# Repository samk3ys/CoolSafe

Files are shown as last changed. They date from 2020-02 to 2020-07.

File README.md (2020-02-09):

# Cool Safe
UKY capstone project

ECE 490 / 491 - 2 Semester Senior Design - Fall 2019 thru Spring 2020

Sponsor: GE Appliances, a Haier Company 
Contact: Choon Jae-Ryu (ChoonJae.Ryu@geappliances.com)

Members: 
  Sam Keys (CPE) 
  Shae Henry (EE) 
  Steven Deaton (EE) 
  Sylvester Okafor (EE) 
  Tylor Mendez (CPE)

Project Summary: 
  Multi-generational living has driven a need for a safe storage for medications in the home. This project aims to develop a lock-bin for use in a refrigerator that is only accessible thru a biometric identification (or physical key for backup). Also to create a mobile app that can display authorized users and add / delete / disable these users.

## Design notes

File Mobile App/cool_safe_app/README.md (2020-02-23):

# cool_safe_app

A new Flutter application.

## Getting Started

This project is a starting point for a Flutter application.

A few resources to get you started if this is your first Flutter project:

- [Lab: Write your first Flutter app](https://flutter.dev/docs/get-started/codelab)
- [Cookbook: Useful Flutter samples](https://flutter.dev/docs/cookbook)

For help getting started with Flutter, view our
[online documentation](https://flutter.dev/docs), which offers tutorials,
samples, guidance on mobile development, and a full API reference.

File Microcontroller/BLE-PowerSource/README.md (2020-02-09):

# BLE-PowerSource

A Particle project named BLE-PowerSource

## Welcome to your project!

Every new Particle project is composed of 3 important elements that you'll see have been created in your project directory for BLE-PowerSource.

#### ```/src``` folder:  
This is the source folder that contains the firmware files for your project. It should *not* be renamed. 
Anything that is in this folder when you compile your project will be sent to our compile service and compiled into a firmware binary for the Particle device that you have targeted.

If your application contains multiple files, they should all be included in the `src` folder. If your firmware depends on Particle libraries, those dependencies are specified in the `project.properties` file referenced below.

#### ```.ino``` file:
This file is the firmware that will run as the primary application on your Particle device. It contains a `setup()` and `loop()` function, and can be written in Wiring or C/C++. For more information about using the Particle firmware API to create firmware for your Particle device, refer to the [Firmware Reference](https://docs.particle.io/reference/firmware/) section of the Particle documentation.

#### ```project.properties``` file:  
This is the file that specifies the name and version number of the libraries that your project depends on. Dependencies are added automatically to your `project.properties` file when you add a library to a project using the `particle library add` command in the CLI or add a library in the Desktop IDE.

## Adding additional files to your project

#### Projects with multiple sources
If you would like add additional files to your application, they should be added to the `/src` folder. All files in the `/src` folder will be sent to the Particle Cloud to produce a compiled binary.

#### Projects with external libraries
If your project includes a library that has not been registered in the Particle libraries system, you should create a new folder named `/lib/<libraryname>/src` under `/<project dir>` and add the `.h`, `.cpp` & `library.properties` files for your library there. Read the [Firmware Libraries guide](https://docs.particle.io/guide/tools-and-features/libraries/) for more details on how to develop libraries. Note that all contents of the `/lib` folder and subfolders will also be sent to the Cloud for compilation.

## Compiling your project

When you're ready to compile your project, make sure you have the correct Particle device target selected and run `particle compile <platform>` in the CLI or click the Compile button in the Desktop IDE. The following files in your project folder will be sent to the compile service:

- Everything in the `/src` folder, including your `.ino` application file
- The `project.properties` file for your project
- Any libraries stored under `lib/<libraryname>/src`

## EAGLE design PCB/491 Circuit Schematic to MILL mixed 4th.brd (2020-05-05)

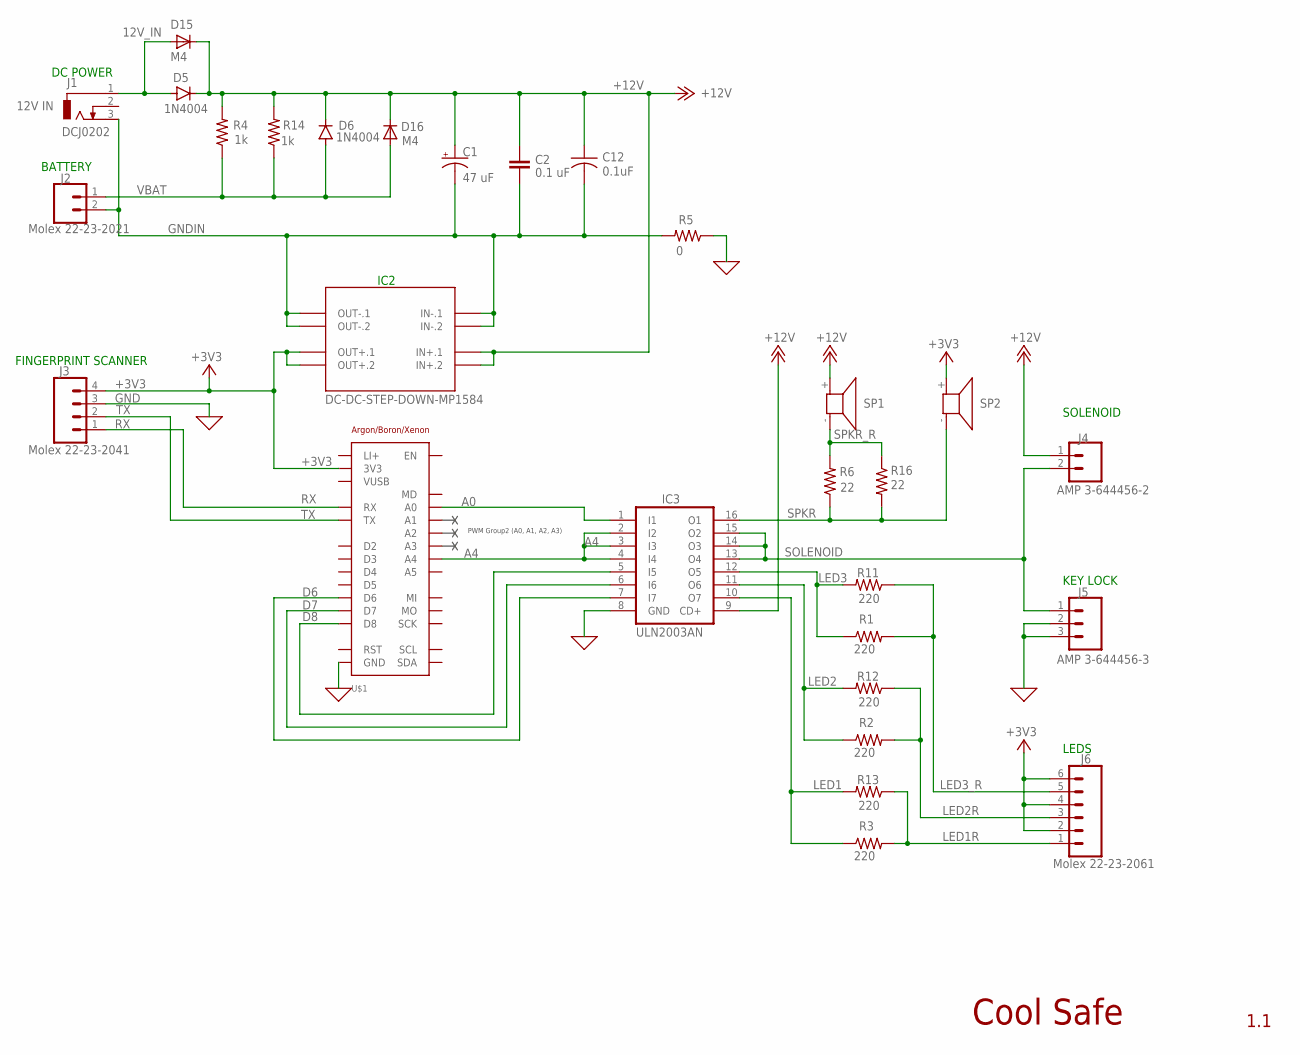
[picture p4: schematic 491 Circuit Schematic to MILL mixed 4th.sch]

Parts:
C1: 47 uF; E2,5-6
C2: 0.1 uF; C2.5-5
C12: 0.1uF; C1206
D5, D6: 1N4004; DO41-10
D15, D16: M4; SMA-DO214AC
IC2: DC-DC-STEP-DOWN-MP1584
IC3: ULN2003AN; DIL16
J1: DCJ0202
J2: Molex 22-23-2021; MOLEX-1X2
J3: Molex 22-23-2041; MOLEX-1X4
J4: AMP 3-644456-2; 1X02
J5: AMP 3-644456-3; 1X03
J6: Molex 22-23-2061; MOLEX-1X6
R1, R2, R3: 220; 0207/10
R4: 1k; 0207/10
R5: 0; 0207/10
R6: 22; 0204/7
R11, R12, R13: 220; M1206
R14: 1k; M1206
R16: 22; M1206
SP1, SP2: KSS1201
U$1: TEMPLATE_ARGON/BORON/XENONPTH; NO_PADS

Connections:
12V_IN: D5.A, D15.A, J1.1
+3V3: IC2.OUT+.1, IC2.OUT+.2, J3.4, J6.2, J6.4, J6.6, SP2.+ (1), U$1.P$14 (3V3)
+12V: C1.+, C2.1, C12.1, D5.C, D6.C, D15.K (C), D16.K (C), IC2.IN+.1, IC2.IN+.2, IC3.9 (CD+), J4.1, R4.2, R14.2, SP1.+ (1)
A0: IC3.1 (I1), U$1.P$17 (A0)
A4: IC3.2 (I2), IC3.3 (I3), IC3.4 (I4), U$1.P$21 (A4)
D6: IC3.7 (I7), U$1.P$6 (D6)
D7: IC3.6 (I6), U$1.P$5 (D7)
D8: IC3.5 (I5), U$1.P$4 (D8)
GND: IC3.8 (GND), J3.3, J5.2, J5.3, R5.1, U$1.P$16 (GND)
GNDIN: C1.-, C2.2, C12.2, IC2.IN-.1, IC2.IN-.2, IC2.OUT-.1, IC2.OUT-.2, J1.3, J2.2, R5.2
LED1: IC3.10 (O7), R3.1, R13.2
LED1R: J6.1, R3.2, R13.1
LED2: IC3.11 (O6), R2.1, R12.2
LED2R: J6.3, R2.2, R12.1
LED3: IC3.12 (O5), R1.1, R11.2
LED3_R: J6.5, R1.2, R11.1
RX: J3.1, U$1.P$26 (RX)
SOLENOID: IC3.13 (O4), IC3.14 (O3), IC3.15 (O2), J4.2, J5.1
SPKR: IC3.16 (O1), R6.1, R16.2, SP2.- (2)
SPKR_R: R6.2, R16.1, SP1.- (2)
TX: J3.2, U$1.P$27 (TX)
VBAT: D6.A, D16.A, J2.1, R4.1, R14.1

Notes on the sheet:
PWM Group2 (A0, A1, A2, A3)
1.1
Cool Safe
12V IN
SOLENOID
KEY LOCK
LEDS
BATTERY
FINGERPRINT SCANNER
IC2
DC POWER

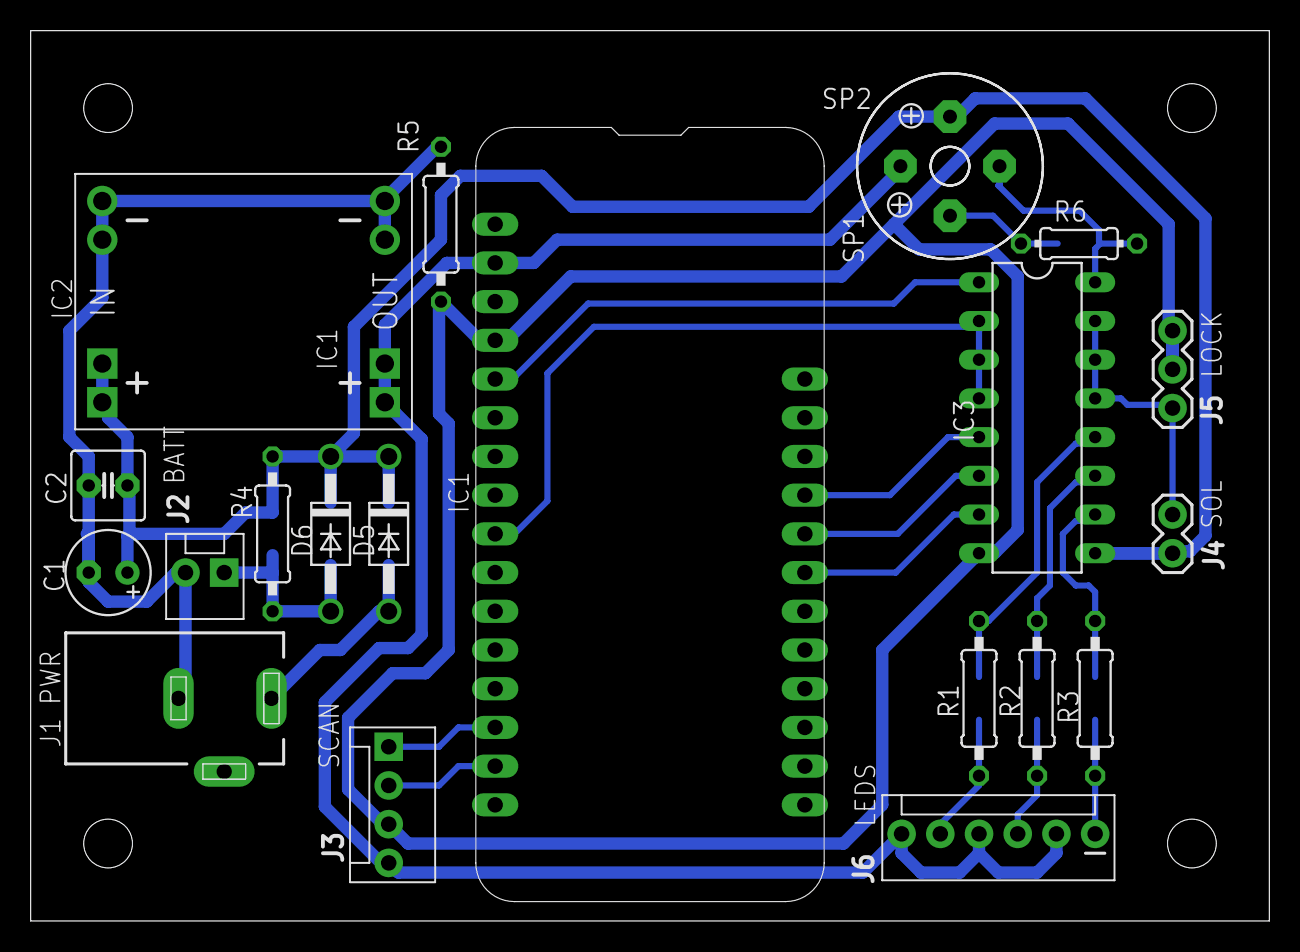
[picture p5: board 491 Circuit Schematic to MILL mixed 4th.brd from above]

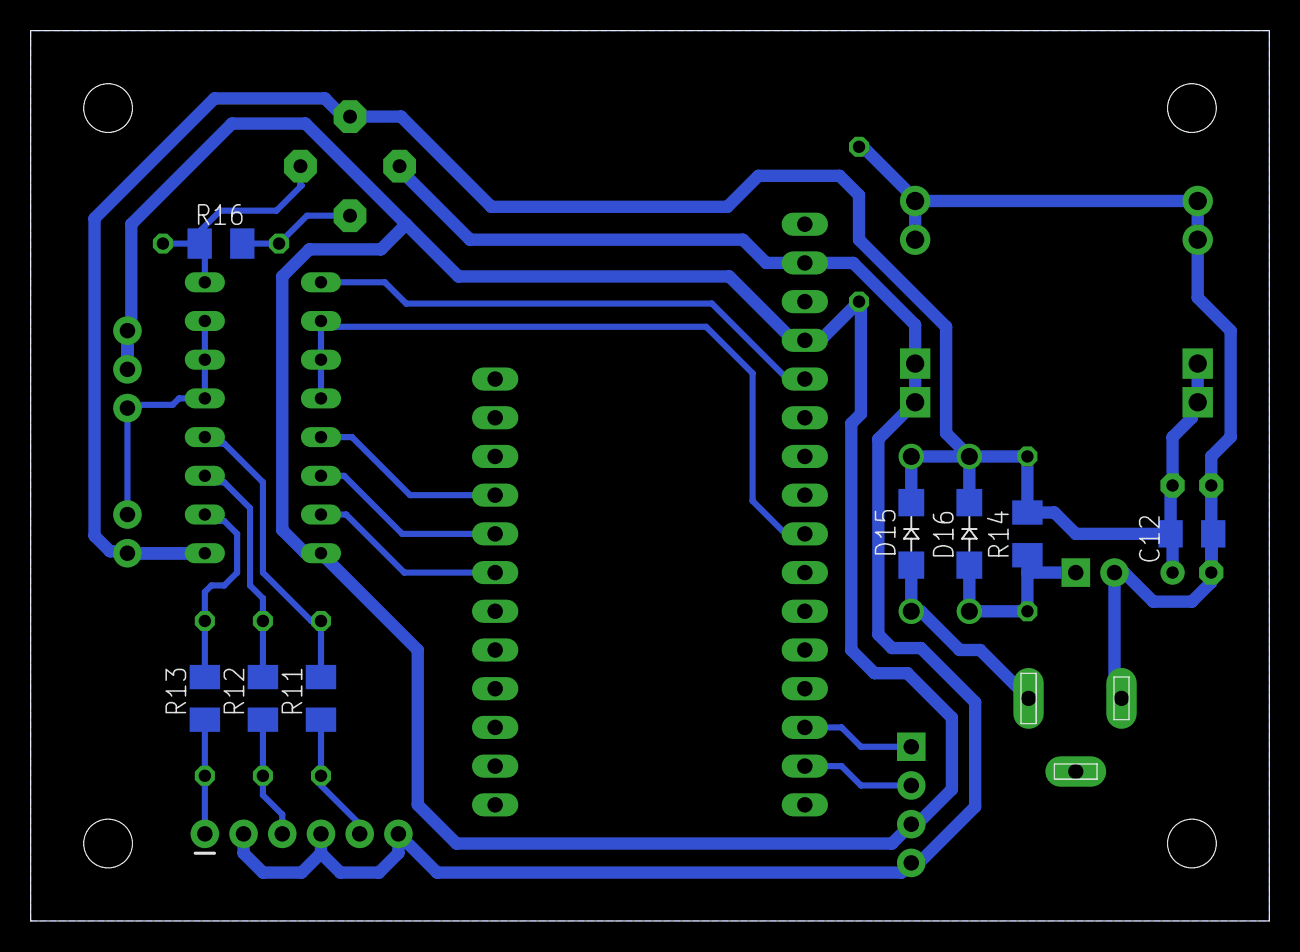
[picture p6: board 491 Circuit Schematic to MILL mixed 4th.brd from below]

Board: 2 copper layers, 81.3 x 58.4 mm, 29 parts (8 on the bottom side), 22 nets.

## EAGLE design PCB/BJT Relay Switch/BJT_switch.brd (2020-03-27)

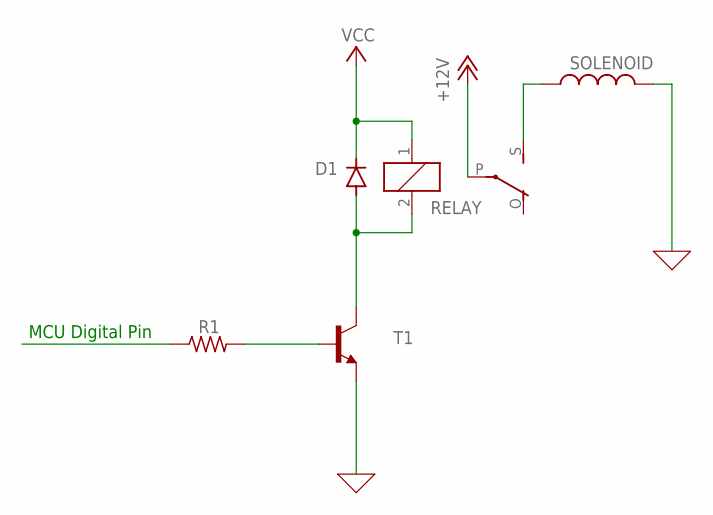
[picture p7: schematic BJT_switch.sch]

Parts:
D1: 1N4004; DO41-10
L1: SOLENOID; 0207/5V
R1: R-US_0204/7; 0204/7
RELAY: ZF112
T1: -NPN-TO92; TO92

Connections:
0: L1.2, T1.1 (E)
+12V: RELAY.P
unnamed: L1.1, RELAY.S
unnamed: R1.2, T1.2 (B)
unnamed: D1.A, RELAY.2, T1.3 (C)
VCC: D1.C, RELAY.1

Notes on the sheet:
MCU Digital Pin

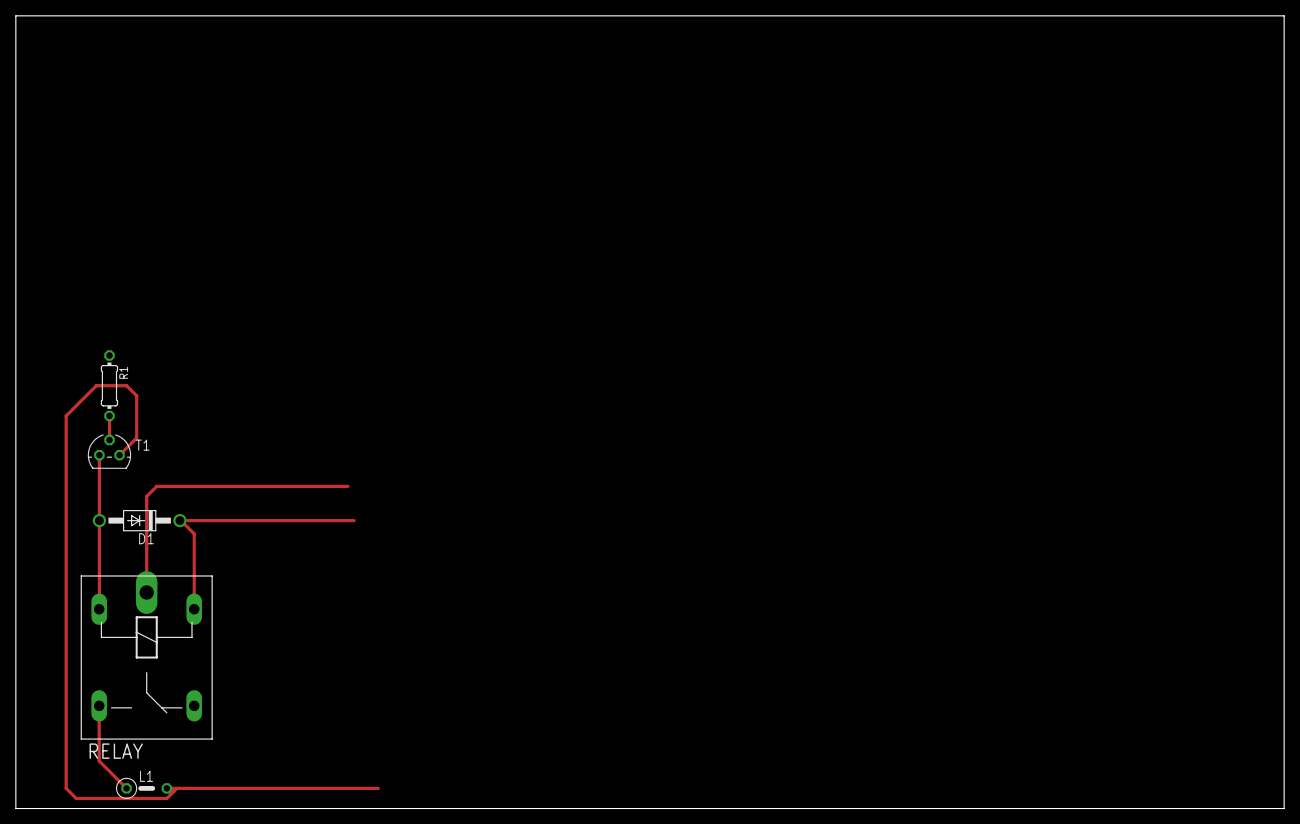
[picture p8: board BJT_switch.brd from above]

Board: 2 copper layers, 160.0 x 100.0 mm, 5 parts (0 on the bottom side), 5 nets.

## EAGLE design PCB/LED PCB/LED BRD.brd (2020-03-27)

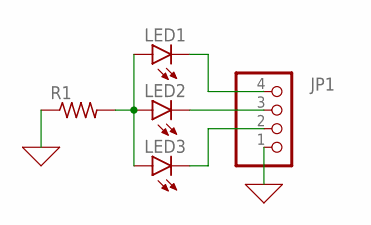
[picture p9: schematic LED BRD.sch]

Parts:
JP1: PINHD-1X4; 1X04
LED1, LED2, LED3: LED5MM
R1: R-US_0204/7; 0204/7

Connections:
0: JP1.1, R1.1
unnamed: LED1.A, LED2.A, LED3.A, R1.2
unnamed: JP1.2, LED3.K (C)
unnamed: JP1.4, LED1.K (C)
unnamed: JP1.3, LED2.K (C)

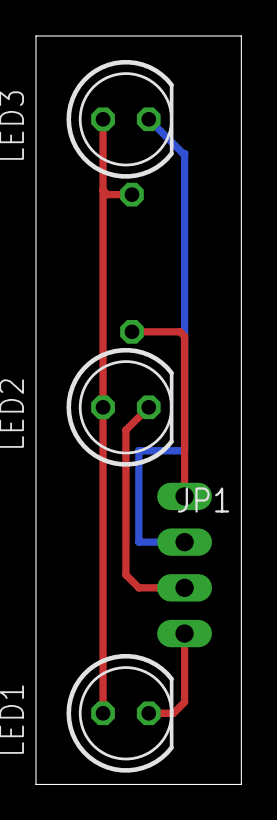
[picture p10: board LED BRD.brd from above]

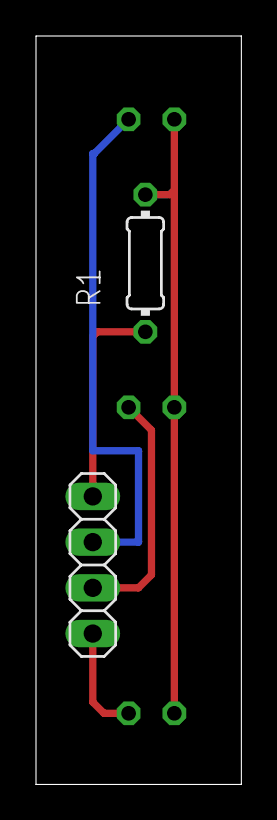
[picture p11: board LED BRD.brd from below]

Board: 2 copper layers, 11.4 x 41.6 mm, 5 parts (2 on the bottom side), 5 nets.

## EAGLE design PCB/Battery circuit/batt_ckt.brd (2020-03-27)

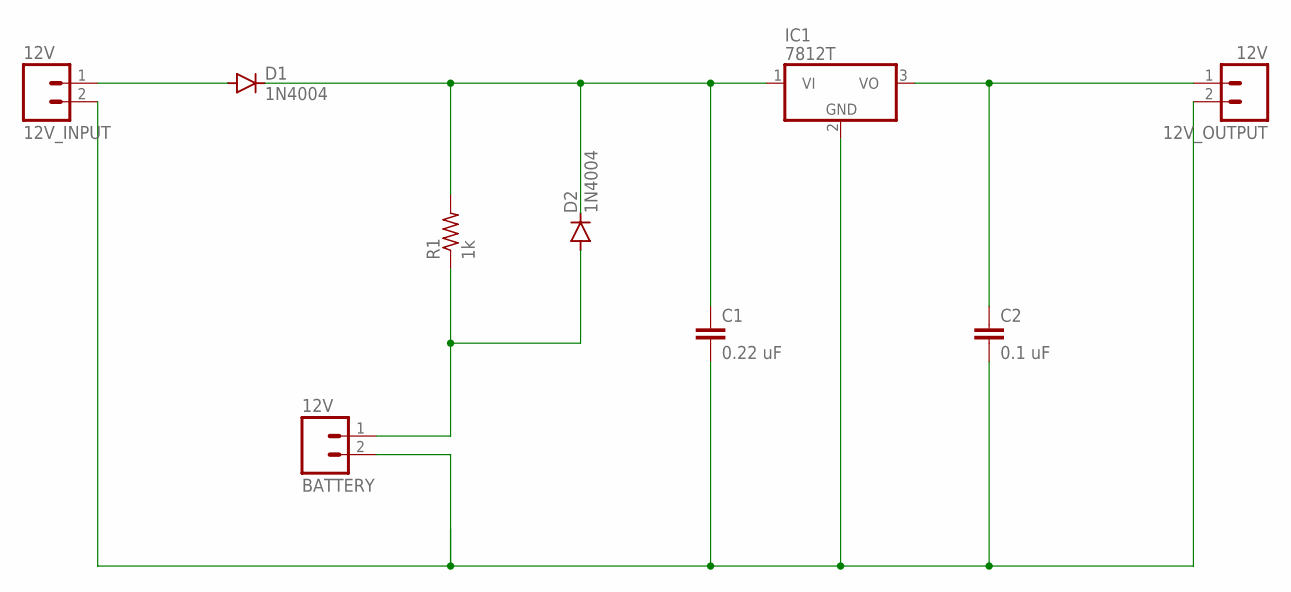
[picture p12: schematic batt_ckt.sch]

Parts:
12V_INPUT, 12V_OUTPUT: 12V; 02P
BATTERY: 12V; 02P
C1: 0.22 uF; C2.5-5
C2: 0.1 uF; C2.5-5
D1, D2: 1N4004; DO41-10
IC1: 7812T; TO220H
R1: 1k; 0207/10

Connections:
unnamed: BATTERY.1, D2.A, R1.1
unnamed: C1.1, D1.C, D2.C, IC1.1 (VI), R1.2
unnamed: 12V_INPUT.1, D1.A
unnamed: 12V_INPUT.2, 12V_OUTPUT.2, BATTERY.2, C1.2, C2.2, IC1.2 (GND)
unnamed: 12V_OUTPUT.1, C2.1, IC1.3 (VO)

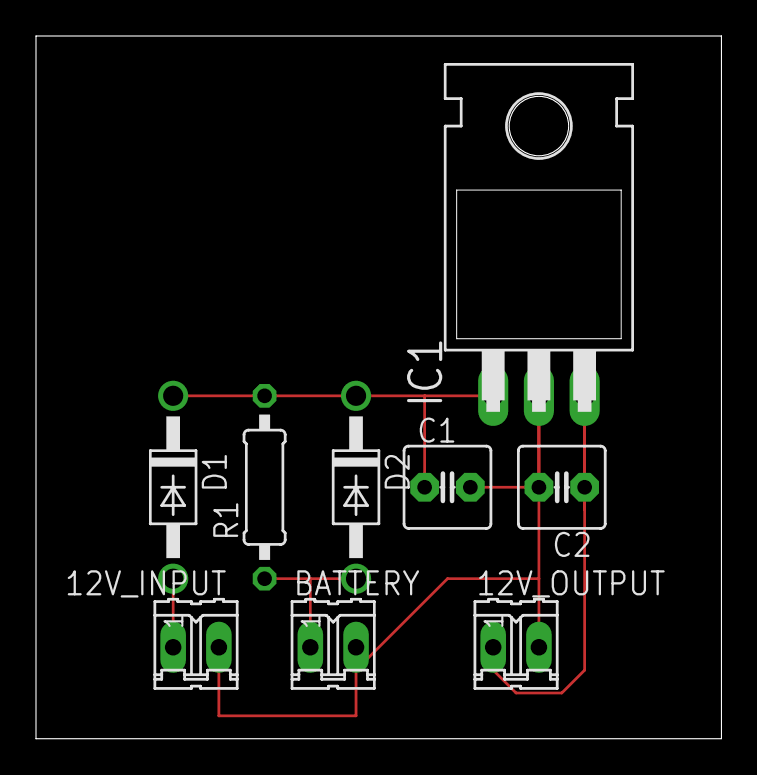
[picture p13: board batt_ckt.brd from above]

Board: 2 copper layers, 38.1 x 39.0 mm, 9 parts (0 on the bottom side), 5 nets.

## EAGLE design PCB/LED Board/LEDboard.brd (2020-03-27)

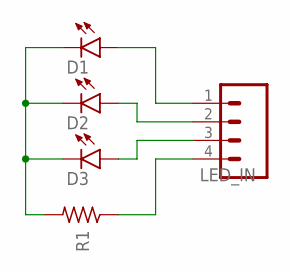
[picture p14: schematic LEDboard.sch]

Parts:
D1, D2, D3: LED5MM
LED_IN: M04; 04P
R1: R-US_0204/7; 0204/7

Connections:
unnamed: D3.A, LED_IN.3
unnamed: D2.A, LED_IN.2
unnamed: D1.A, LED_IN.1
unnamed: D1.K (C), D2.K (C), D3.K (C), R1.2
unnamed: LED_IN.4, R1.1

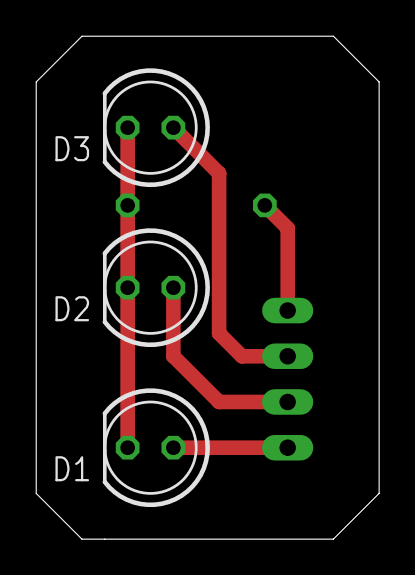
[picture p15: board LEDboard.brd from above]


Board: 2 copper layers, 19.1 x 27.9 mm, 5 parts (2 on the bottom side), 5 nets.

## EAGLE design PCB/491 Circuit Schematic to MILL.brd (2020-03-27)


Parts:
C1: 47 uF; E2,5-6
C2: 0.1 uF; C2.5-5
D4, D5, D6: 1N4004; DO41-10
J1: DCJ0202
JP1: PINHD-1X4/90; 1X04/90
JP3: PINHD-1X4; 1X04
LOCK_SWITCH: LOCK_SWITCHSCREW_TERMINAL; 1751248
R2: R-US_0207/10; 0207/10
R3, R5, R6: R-US_0204/7; 0204/7
R4: 1k; 0207/10
RELAY: ZF112
SOLENOID: PINHD-1X2; 1X02
SP1: KSS1201
T1, T2: -NPN-TO92; TO92
U$1: TEMPLATE_ARGON/BORON/XENONFEATHER_ONLY; FEATHER_ONLY
U$2: DC-DC-STEP-DOWN-MP1584
X2: 1751248

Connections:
0: C1.-, C2.2, J1.3, JP1.1, JP3.3, R2.1, SOLENOID.2, T1.1 (E), T2.1 (E), U$1.16B (GND), U$1.16T (GND), U$1.P$16 (GND), U$2.IN-.1, U$2.IN-.2, U$2.OUT-.1, U$2.OUT-.2, X2.1
+3V3: D4.C, JP3.4, LOCK_SWITCH.2, RELAY.1, U$1.14B (3V3), U$1.14T (3V3), U$1.P$14 (3V3), U$2.OUT+.1, U$2.OUT+.2
+12V: C1.+, C2.1, D5.C, D6.C, R4.2, RELAY.P, SP1.+ (1), U$2.IN+.1, U$2.IN+.2
unnamed: D6.A, R4.1, X2.2
unnamed: R5.2, T2.2 (B)
unnamed: R5.1, U$1.17B (A0), U$1.17T (A0), U$1.P$17 (A0)
unnamed: JP1.4, U$1.06B (D6), U$1.06T (D6), U$1.P$6 (D6)
unnamed: JP1.3, U$1.05B (D7), U$1.05T (D7), U$1.P$5 (D7)
unnamed: JP1.2, U$1.04B (D8), U$1.04T (D8), U$1.P$4 (D8)
unnamed: LOCK_SWITCH.1, R2.2, U$1.07B (D5), U$1.07T (D5), U$1.P$7 (D5)
unnamed: D4.A, RELAY.2, T1.3 (C)
unnamed: RELAY.S, SOLENOID.1
unnamed: R6.1, T2.3 (C)
unnamed: JP3.1, U$1.26B (RX), U$1.26T (RX), U$1.P$26 (RX)
unnamed: R3.2, T1.2 (B)
unnamed: R3.1, U$1.21B (A4), U$1.21T (A4), U$1.P$21 (A4)
unnamed: JP3.2, U$1.27B (TX), U$1.27T (TX), U$1.P$27 (TX)
unnamed: D5.A, J1.1
unnamed: R6.2, SP1.- (2)

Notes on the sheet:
PWM Group2 (A0, A1, A2, A3)
COMM
Fingerprint Scanner
1.1
Cool Safe
12V IN
BATTERY


Board: 2 copper layers, 95.2 x 77.5 mm, 22 parts (0 on the bottom side), 19 nets.

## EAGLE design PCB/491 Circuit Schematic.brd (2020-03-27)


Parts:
12V_EXT, 12V_IN: 12V; 02P
B1, B2, B3: SL-340/P3.6V
BATTERY: 12V; 02P
BATTERY_EXT: 12V; 02P
C1: 47 uF; E2,5-6
C2: 0.1 uF; C2.5-5
D1, D2, D3: U57X32
D4, D5, D6: 1N4004; DO41-10
L2: SOLENOID; 0207/5V
LOCK_SWITCH: LOCK_SWITCH; SWITCH_TERMINAL
R1, R2, R3, R5, R6: R-US_0204/7; 0204/7
R4: 1k; 0207/10
RELAY: SRD-05VDC-SL-C; RELAY_SRD-05VDC-SL-C
SP1: KSS1201
T1, T2: -NPN-TO92; TO92
U$1: TEMPLATE_ARGON/BORON/XENONFEATHER_ONLY; FEATHER_ONLY
U$2: DC-DC-STEP-DOWN-MP1584
U$3: FPS; JST

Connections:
0: 12V_EXT.2, 12V_IN.2, B1.-, BATTERY.2, BATTERY_EXT.2, C1.-, C2.2, L2.2, R1.1, R2.1, T1.1 (E), T2.1 (E), U$1.16B (GND), U$1.16T (GND), U$2.IN-.1, U$2.IN-.2, U$2.OUT-.1, U$2.OUT-.2, U$3.3 (GND)
+3V3: D4.C, LOCK_SWITCH.P$1, RELAY.A1, U$1.14B (3V3), U$1.14T (3V3), U$2.OUT+.1, U$3.4 (VCC)
FPS: R6.2, SP1.- (2)
unnamed: B2.+, B3.-
unnamed: R5.1, U$1.17B (A0), U$1.17T (A0)
unnamed: B1.+, B2.-
unnamed: D1.A, U$1.06B (D6), U$1.06T (D6)
unnamed: D2.A, U$1.05B (D7), U$1.05T (D7)
unnamed: D3.A, U$1.04B (D8), U$1.04T (D8)
unnamed: LOCK_SWITCH.P$2, R2.2, U$1.07B (D5), U$1.07T (D5)
unnamed: D1.K (C), D2.K (C), D3.K (C), R1.2
unnamed: D4.A, RELAY.A2, T1.3 (C)
unnamed: L2.1, RELAY.NO
unnamed: BATTERY.1, D6.A, R4.1
unnamed: U$1.26B (RX), U$1.26T (RX), U$3.1 (TX)
unnamed: R3.2, T1.2 (B)
unnamed: R3.1, U$1.21B (A4), U$1.21T (A4)
unnamed: U$1.18B (A1), U$1.18T (A1)
unnamed: U$1.19B (A2), U$1.19T (A2)
unnamed: U$1.20B (A3), U$1.20T (A3)
unnamed: U$1.27B (TX), U$1.27T (TX), U$3.2 (RX)
unnamed: 12V_IN.1, D5.A
unnamed: B3.+, BATTERY_EXT.1
unnamed: R6.1, T2.3 (C)

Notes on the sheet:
PWM Group2 (A0, A1, A2, A3)
COMM
Fingerprint Scanner
3S Li-ion Battery Pack (11.1V)
1.1
Cool Safe

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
Board: 2 copper layers, 28 parts (0 on the bottom side), 24 nets, no tracks yet.

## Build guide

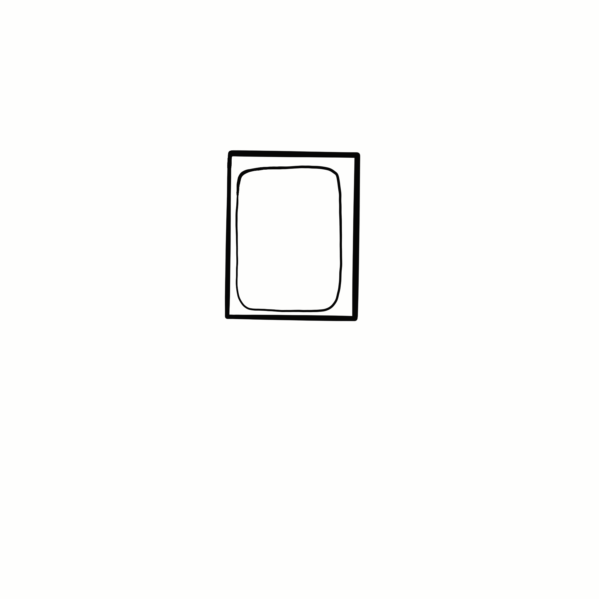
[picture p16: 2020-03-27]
Mobile App/cool_safe_app/assets/images/RegistrationGuide.gif

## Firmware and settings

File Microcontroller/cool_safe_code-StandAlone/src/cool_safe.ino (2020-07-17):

/*
 * Project: Cool Safe Code
 * Description: Main code that runs our senior capstone project for UK. It is a lock-bin locked by a solenoid that also has a fingerprint scanner and app to register fingerprints
 * Author: Sam Keys, Sylvester Okafor, Tylor Mendez, Shae Henry, Steven Deaton
 * Date: Spring 2020
 */

#include "Particle.h"                         // library for Particle devices (we are using a Particle Xenon)
#include "FPS_GT521F32_Particle.h"            // library for fingerprint scanner functions
#include "playTones.h"                        // library for playing sounds on a buzzer / speaker

// Globals and timings
SYSTEM_MODE(MANUAL);                          // Avoid Particle registration. Can't use BLE out-of-the-box without MANUAL control. Could changed to AUTOMATIC for easier cloud integration in the future.
bool keySwitchFlag = false;                   // tracks state of the manual key switch to limit use to once per turn
const int maxUsers = 200;                     // Maximum number of users able to be enrolled on the FPS
const int unlockTime = 1000;                  // milliseconds to keep solenoid powered (pulled in) when opening the lock-bin
const int delayTime = 100;                    // milliseconds to delay after a round of the main infinite loop
const unsigned long ENROLLMENT_WAIT = 60;     // seconds to wait for fingerprint enrollment
unsigned long enrollStartTime = 0;            // tracks time since an enrollment started
unsigned long enrollmentWatch = 0;            // tracks how much time has passed while waiting for fingerprint enrollment

// I/O
const int buzzer    = A0;                     // digital pin for sound output
const int solenoid  = A4;                     // digital pin for relay/driver signal. HIGH connects to normally open, LOW connects to normally closed
const int keySwitch = D5;                     // digital pin for the electro-mechanical switch with a key. Backup to fps.
const int greenLED  = D6;                     // green LED signifies an authorized
const int busyLED   = D7;                     // amber LED signifies the system is busy (usually with registration mode). Same as the Xenon's on-board blue LED
const int redLED    = D8;                     // red LED signifies an unauthorized user
FPS_GT521F32 fps;                             // fingerprint scanner module - uses Serial1 (Rx:pin14, Tx:pin15)

// Buzzer songs
int startSound[]    = {NOTE_C3, NOTE_C4, NOTE_D4, NOTE_C5, NOTE_D5, NOTE_C6};   // plays when the system boots up
int startDuration[] = {2, 4, 4, 4, 4, 1};
int goodSound[]     = {NOTE_C3, NOTE_E3, NOTE_G3};                              // plays when the lock-bin is unlocked
int goodDuration[]  = {4, 4, 1};
int badSound[]      = {NOTE_G3, NOTE_E3, NOTE_C3};                              // plays when access to the lock-bin is denied
int badDuration[]   = {4, 4, 1};

// Operation function prototypes
bool addUser(void);
bool removeUser(uint8_t id);
bool deauthorizeUser(uint8_t id);
bool authorizeUser(uint8_t id);
bool changeUserName(uint8_t id, String name);

int manualEnrollTimer = 0;  // tracks time for manually initiating enrollment with the key switch
int manualEnrollTriggerTime = 500;  // time (in ms) alotted for triggering manual enrollment

void openBin() {
  // Open the lock-bin by connecting the relays common and normally open, actuating the solenoid.
  digitalWrite(solenoid, HIGH);        // Unlock the bin
  goodFeedback();                   // Use lights and sounds to let the user know the lock-bin is unlocked
  delay(unlockTime);                // How long the solenoid stays pulled in
  digitalWrite(solenoid, LOW);         // Solenoid is back out, ready to lock again
}

void goodFeedback() {
  // green light and good sound
  digitalWrite(greenLED, HIGH);                                 // external green light
  RGB.color(0, 255, 0);                                         // on-board green light
  play(buzzer, arraySize(goodSound), goodSound, goodDuration);  // sound has some delay
  digitalWrite(greenLED, LOW);                                  // turn lights back off
  RGB.color(0, 0, 0);
}

void badFeedback() {
  // red light and bad sound
  digitalWrite(redLED, HIGH);                                   // external red light
  RGB.color(255, 0, 0);                                         // on-board red light
  play(buzzer, arraySize(badSound), badSound, badDuration);     // sound has some delay
  digitalWrite(redLED, LOW);                                    // turn lights back off
  RGB.color(0, 0, 0);
}

void enrollScanFeedback() {
  // Blink amber (busy) LED and make a sound to signify a scan has been taken and the user can remove their finger
  int sound[] = {NOTE_C3, NOTE_E3};
  int duration[] = {2, 2};
  play(buzzer, 2, sound, duration);
  digitalWrite(busyLED, LOW);
  RGB.color(0, 0, 0);
  delay(100);
  digitalWrite(busyLED, HIGH);
  RGB.color(100, 100, 0);
}

int identifyUser() {
  // Once a finger is detected then identify a user with the FPS
  //fps.CaptureFinger(false);   // false = take a low quality image (faster)
  fps.CaptureFinger(true);
  int id = fps.Identify1_N(); // check if the fingerprint is stored in the FPS

  if (id >= 0 && id < 200) {  // valid value for a user id on the GT-521F32 FPS
    Serial.print("Verified ID:");
    Serial.println(id);
    openBin();  // Allow access. Includes good feedback
  }
  else {//if unable to recognize
    Serial.println("Finger not found");
    badFeedback();  // Deny access
  }

  return id;  // Return id of the user from the FPS
}

bool enrollUser() {
  // Enroll a new fingerprint for the scanner. Returns true if successful. Returns false if timed out or error.

  // Signal to users that the system is busy. Normal functions won't work at this time
  digitalWrite(busyLED, HIGH);
  RGB.color(100, 100, 0);
 
  // Is there room?
  if (fps.GetEnrollCount() == maxUsers) {  // FPS full
    Serial.println("Error: no more enrollment IDs available.");
    digitalWrite(busyLED, LOW);
    RGB.color(0, 0, 0);
    return false;
  }

  // Jot down the time this enrollment started.
  enrollStartTime = millis();

  int enrollid = 0;
  bool usedid = true;
  while (usedid == true) {
    usedid = fps.CheckEnrolled(enrollid);
    if (usedid==true) enrollid++;
  }
  Serial.printlnf("ID #%d is next available on FPS.", enrollid);

  Serial.println("start Enroll");
  fps.EnrollStart(enrollid);
  Serial.println("Enroll started");

  // enroll w/ 3 seperate scans
  Serial.print("Press finger to Enroll #");
  Serial.println(enrollid);
  while(fps.IsPressFinger() == false) {
    if ( (millis() - enrollStartTime) >= (ENROLLMENT_WAIT * 1000) ) {
      digitalWrite(busyLED, LOW);
      RGB.color(0, 0, 0);
      return false; // exit w/ timeout function if we've been here for too long
    }
    delay(100);
  }
  bool bret = fps.CaptureFinger(true);  // true = use high quality scan
  int iret = 0;
  if (bret != false) {
    // Successful first scan
    enrollScanFeedback();  //goodFeedback();
    Serial.println("Remove finger");
    fps.Enroll1(); 
    while(fps.IsPressFinger() == true) delay(100);
    Serial.println("Press same finger again");
    while(fps.IsPressFinger() == false) {
      if ( (millis() - enrollStartTime) >= (ENROLLMENT_WAIT * 1000) ) {
        digitalWrite(busyLED, LOW);
        RGB.color(0, 0, 0);
        return false; // exit w/ timeout function if we've been here for too long
      }
      delay(100);
    }
    bret = fps.CaptureFinger(true);
    if (bret != false) {
      // Successful second scan
      enrollScanFeedback();  //goodFeedback();
      Serial.println("Remove finger");
      fps.Enroll2();
      while(fps.IsPressFinger() == true) delay(100);
      Serial.println("Press same finger yet again");
      while(fps.IsPressFinger() == false)  {
        if ( (millis() - enrollStartTime) >= (ENROLLMENT_WAIT * 1000) ) {
          digitalWrite(busyLED, LOW);
          RGB.color(0, 0, 0);
          return false; // exit w/ timeout function if we've been here for too long
        }
        delay(100);
      }
      bret = fps.CaptureFinger(true);
      if (bret != false) {
        // Successful third scan
        enrollScanFeedback();  //goodFeedback();
        Serial.println("Remove finger");
        iret = fps.Enroll3();
        if (iret == 0) {
          // All scans successful
          goodFeedback();
          Serial.println("Enrolling Successful");
        }
        else {
          // Something went wrong
          badFeedback();
          Serial.print("Enrolling Failed with error code:");
          Serial.println(iret);
          digitalWrite(busyLED, LOW);
          RGB.color(0, 0, 0);
          return false; // stop w/ failure
        }
      }
      else {
        badFeedback();
        Serial.println("Failed to capture third finger");
        digitalWrite(busyLED, LOW);
        RGB.color(0, 0, 0);
        return false; // stop w/ failure
      }
    }
    else {
      badFeedback();
      Serial.println("Failed to capture second finger");
      digitalWrite(busyLED, LOW);
      RGB.color(0, 0, 0);
      return false; // stop w/ failure
    }
  }
  else {
    badFeedback();
    Serial.println("Failed to capture first finger");
    digitalWrite(busyLED, LOW);
    RGB.color(0, 0, 0);
    return false; // stop w/ failure
  }

  // Let the users know the system is back to normal
  digitalWrite(busyLED, LOW);
  RGB.color(0, 0, 0);
  return true;  // exit w/ success
}

void LEDsequence() {
  // Do a wave of all 3 LEDs on and then off. Used for making sure they work at startup
  digitalWrite(greenLED, HIGH);
  delay(100);
  digitalWrite(busyLED, HIGH);
  delay(100);
  digitalWrite(redLED, HIGH);
  delay(500);
  digitalWrite(greenLED, LOW);
  delay(100);
  digitalWrite(busyLED, LOW);
  delay(100);
  digitalWrite(redLED, LOW);
}

void setup() {
  // Debugging
  //Serial.begin(9600);         // Open USB serial port for debugging
  //fps.UseSerialDebug = true;  // Sends messages from FPS to USB Serial for debugging
  // On-board LED control
  RGB.control(true);            // take control of the On-Board RGB LED
  RGB.color(255, 255, 255);     // Format red, green, blue, from 0 to 255
  RGB.brightness(64);           // scales brightness of all three colors, 0-255
  // Check EEPROM
  //Serial.print("EEPROM Available: ");
  //Serial.println(EEPROM.length());    // 4096 bytes available

  // Device I/O
	fps.Open();                   // Send serial command to initialize fps. FPS UART uses Rx (pin 14) & Tx (pin 15) on Particle Xenon. Make sure FPS is connected or the program won't go past this part
  fps.SetLED(true);             // Visual test to make sure the fps is connected. Leave on for being able to detect fingerprints
  pinMode(buzzer, OUTPUT);          // sound buzzer, not necessary for using tone()
  pinMode(solenoid, OUTPUT);        // signal to relay/driver for switching solenoid
  pinMode(keySwitch, INPUT_PULLUP); // detect when the switch is activated w/ a key
  pinMode(greenLED, OUTPUT);        // green access permitted LED
  pinMode(busyLED, OUTPUT);         // amber registration mode LED
  pinMode(redLED, OUTPUT);          // red access denied LED
  
  // Reset System: DO NOT UNCOMMENT UNLESS YOU ARE SURE
  //EEPROM.clear();   // ERASES ALL EEPROM (inits all bits to 1)
  //fps.DeleteAll();  // ERASES FPS ENROLLMENTS

  // Setup done. Signify that the system is ready to be used with some light and sound
  LEDsequence();  // turn all LEDs on at start to make sure they work
  play(buzzer, arraySize(startDuration), startSound, startDuration);  // play start-up sound
}

void loop() {
  RGB.color(0, 0, 255);

  // Check for users trying to access using a fingerprint
  if(fps.IsPressFinger()) {
    RGB.color(255, 255, 255); // white LED for debugging to show that a finger is recognized and the FPS is working on figuring out the user
    identifyUser(); // Is this finger recognized by the FPS. If yes open bin, if no send bad feedback
  }

  // Check for users trying to access using the electro-mechanical tumbler lock switch
  // 2nd PCB: HIGH=open switch, LOW=closed switch
  if (digitalRead(keySwitch) == LOW && keySwitchFlag == false) {     // Key switch turned on
    //openBin();                    // Allow access. Includes good feedback
    goodFeedback();                 // Only need feedback for 2nd PCB onward b/c switch directly connects 12V to solenoid
    keySwitchFlag = true;           // Set flag so we don't unlock again before turning the key off
    
    manualEnrollTimer = millis();
    while ( (millis() - manualEnrollTimer) < manualEnrollTriggerTime) { // Enter registration mode manually by flicking the switch on and off and on quickly      
      if (digitalRead(keySwitch) == HIGH) {   // Key switch turned off
        while ( (millis() - manualEnrollTimer) < manualEnrollTriggerTime) { // wait a max of 500ms
          if (digitalRead(keySwitch) == LOW) {  // Key switch turned on
              enrollUser();
          }
        }
      }
    }
  } 
  else if (digitalRead(keySwitch) == HIGH && keySwitchFlag == true) {  // Key switch turned off
    keySwitchFlag = false;          // Reset flag so the key can be used again
  }

  delay(delayTime);
}

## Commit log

2020-02-09 Print BLE input to USB Serial
2020-02-15 BLE Particle update
    BLE Serial terminal can change LED colors. a=red, b=green, c=blue, anything else=yellow.
2020-02-16 SoftwareSerial Fix
    Instead of trying to use two non-UART digital pins the FPS_GT511C3 library now uses the Serial1 pins. They are labeled Rx and Tx on the Particle Xenon and are pins 14 and 15 respectively. The new library files are called FPS_GT511C3_Xenon.cpp and FPS_GT511C3_Xenon.h
    [FPS_Blink.ino, FPS_Enroll.ino, FPS_GT511C3.cpp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]
2020-02-17 BLE_Demo update
    Send an RGB Hex code to the xenon to change the on-board LED to that color
2020-02-24 Play tones w/ buzzer
    Startup sound, good sound, bad sound, Mario, Doom, & Tetris
    [BLE_demo.ino, FPS_GT511C3_Particle.cpp]
2020-02-29 Added EAGLE PCB Folder
    Includes sch and brd files and a library of custom parts
    [491 Circuit Schematic.brd, 491 Circuit Schematic.sch, BJT_switch.brd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]
2020-02-29 PCB Update
    Added FPS and Voltage Regulator.
    [491 Circuit Schematic.brd, 491 Circuit Schematic.sch]
2020-03-01 PCB V1
    [491 Circuit Schematic.brd, 491 Circuit Schematic.sch]
2020-03-05 Create 491 Circuit Schematic For Actual PCB.sch
    New PCB schematic for actual PCB
    [491 Circuit Schematic For Actual PCB.sch]
2020-03-07 Edited Schematic, started layout
    [491 Circuit Schematic For Actual PCB.brd, 491 Circuit Schematic For Actual PCB.sch, 491 Circuit Schematic.sch]
2020-03-07 Added 5mm LEDs
    [491 Circuit Schematic For Actual PCB.brd]
2020-03-08 Update to PCB
    [491 Circuit Schematic For Actual PCB.brd, 491 Circuit Schematic For Actual PCB.sch, LEDboard.brd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]
2020-03-08 PCB V1
    Pretty much ready to mill. Added a to MILL board and some breakout boards for SMT components so that we only need a single-sided copper clad board.
    [491 Circuit Schematic to MILL.brd, 491 Circuit Schematic to MILL.sch, JST.brd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]
2020-03-09 PCB Edit
    Ready for milling
    [491 Circuit Schematic For Actual PCB.brd, 491 Circuit Schematic to MILL.brd, 491 Circuit Schematic to MILL.sch]
2020-03-10 JST Battery Connector
    Changed battery connector from a screw terminal to a JST connector to make sure it gets plugged in correctly.
    [491 Circuit Schematic For Actual PCB.brd, 491 Circuit Schematic For Actual PCB.sch]
2020-03-10 Added LED PCB
    [LED BRD.brd, LED BRD.sch]
2020-04-01 Minimally working
    PCB put together and most functionality tested. FPS and Key both activate solenoid. Sounds play. Still need to integrate BLE.
2020-04-02 Key only unlocks bin once
    Some general clean-up. Made IdentifyUser() a function for identifying a user with the FPS. Modified main loop so that the key only unlocks the bun once by adding a flag to keep track of when the key'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
2020-04-02 Added startup LED sequence
    Turns all external LEDs on at boot-up to make sure they work. Goes on and off in a wave green -> amber -> red. Then the startup sound plays to let the user know the system is ready to use
2020-04-04 Manual enrollment option
    If you turn the key switch on and off quickly (~500 ms) then the system will enter registration mode to enroll a new fingerprint
2020-04-08 60 sec enroll timeout
    The system will only wait for fingerprints enrollment for a minute, then resume normal operation if nothing shows up in that time.
2020-04-11 Enrollment scans blink amber
    Changed code to blink amber LED instead of green after each scan during enrollment. Still blinks red or green to signify fail or success at the end of enrollment
    [cool_safe.ino]
2020-05-05 EE 569 PCB
    Improved design with help from John Barnes
    [491 Circuit Schematic to MILL mixed 4th.brd, 491 Circuit Schematic to MILL mixed 4th.sch]

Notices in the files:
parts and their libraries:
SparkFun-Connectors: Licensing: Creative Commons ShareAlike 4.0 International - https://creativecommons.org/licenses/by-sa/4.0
